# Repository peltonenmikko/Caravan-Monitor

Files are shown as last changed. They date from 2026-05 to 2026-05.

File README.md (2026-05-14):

# Caravan-Monitor
For monitoring caravan stuff

This is an STM32 powered monitoring station for different kinds of sensors made with caravans in mind.
It is powered by 12v car batteries. All other are off the board and connected with wires.

It shows the values on a cheap I²C OLED display and there is one button to browse the values.
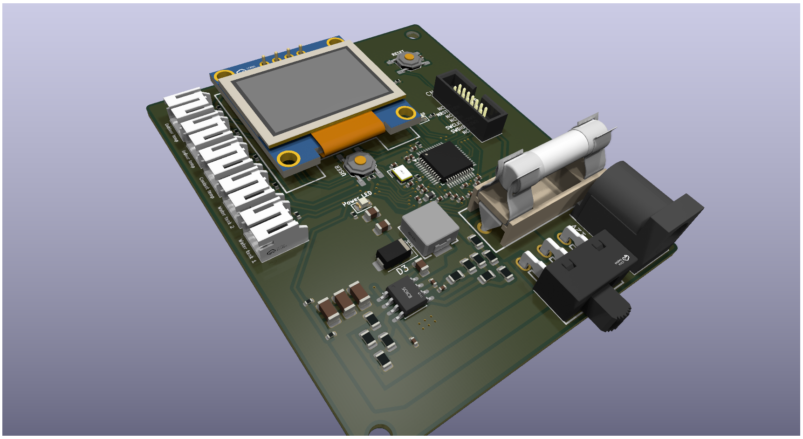
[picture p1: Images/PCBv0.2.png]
Version 0.2 of PCB


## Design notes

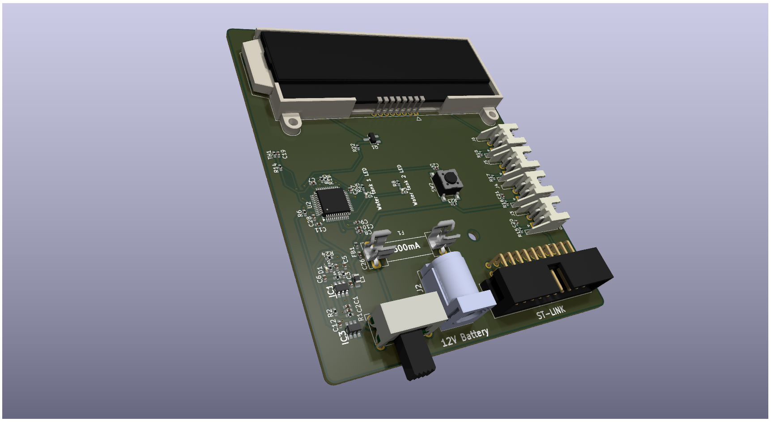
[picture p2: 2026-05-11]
Images/PCB.png

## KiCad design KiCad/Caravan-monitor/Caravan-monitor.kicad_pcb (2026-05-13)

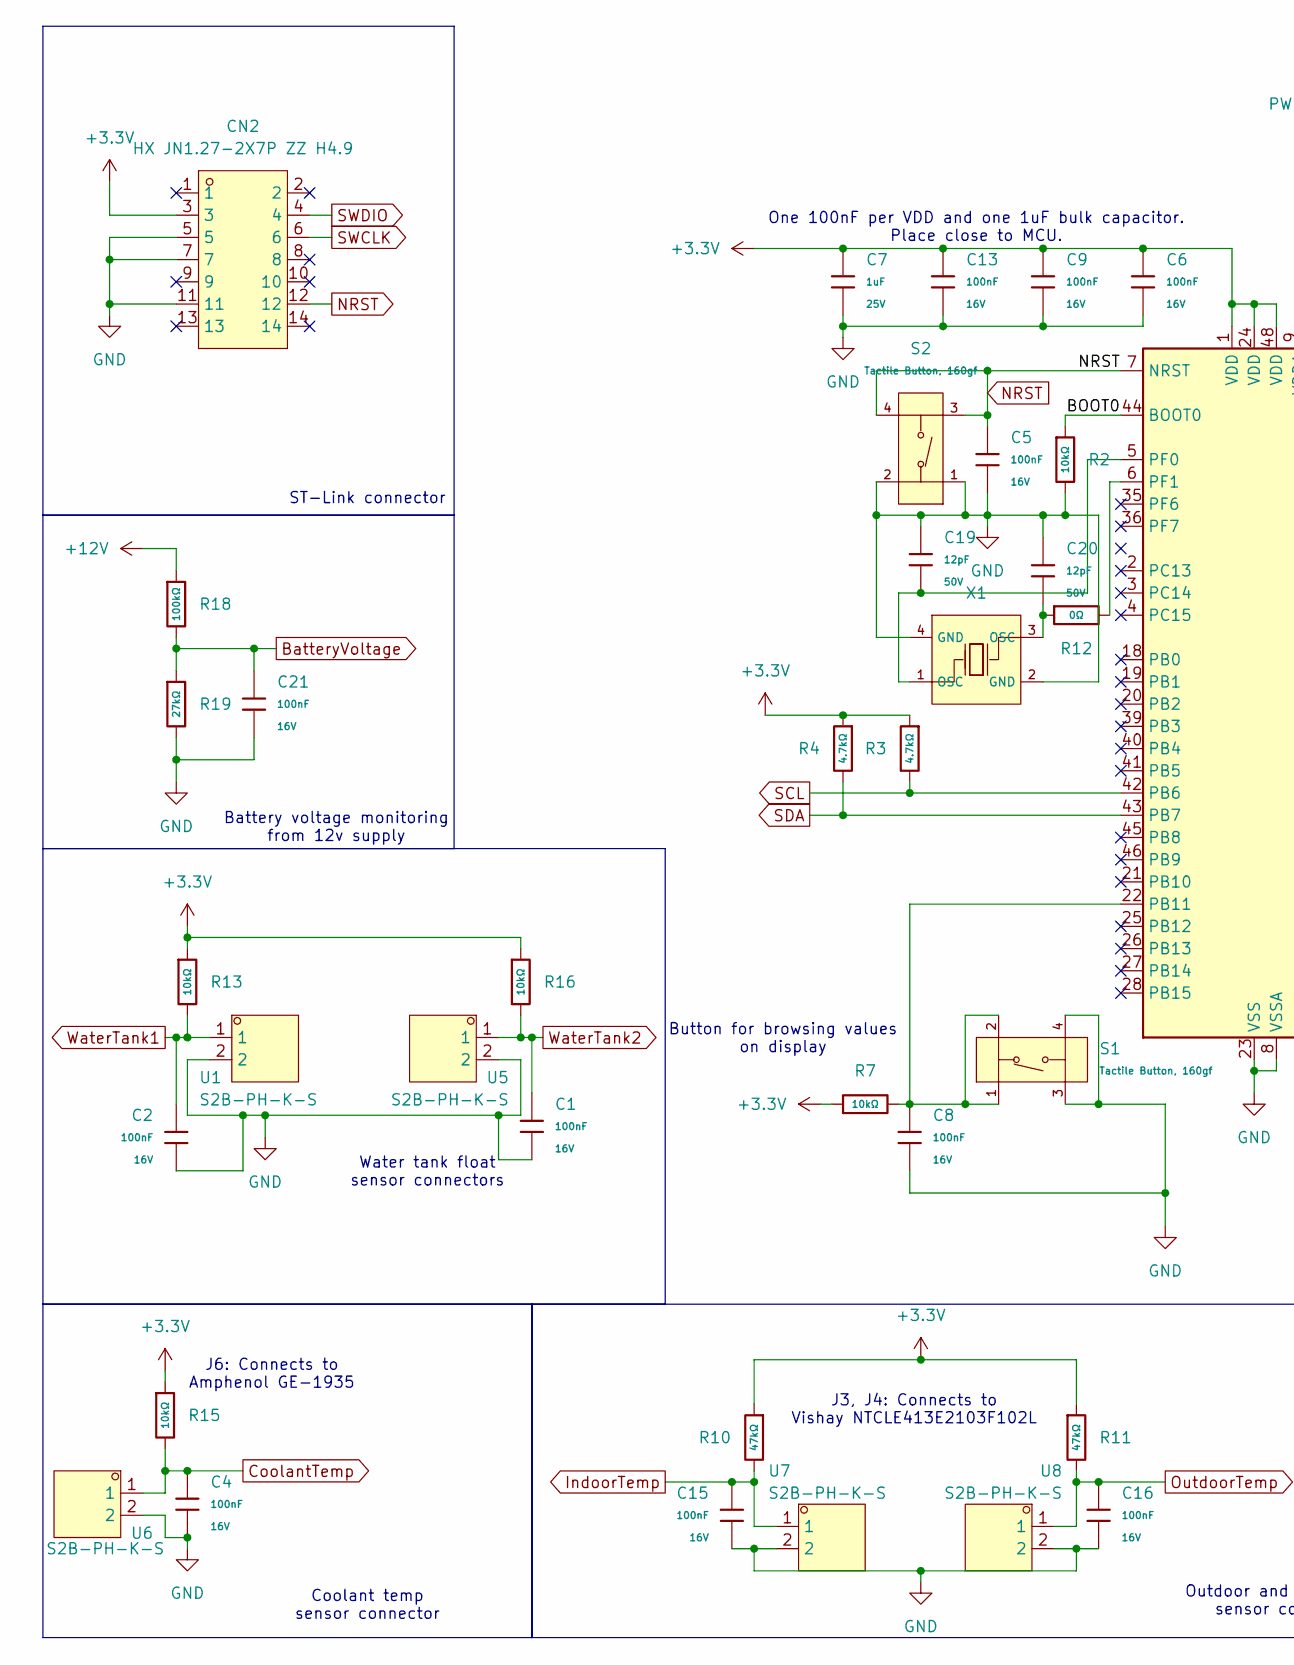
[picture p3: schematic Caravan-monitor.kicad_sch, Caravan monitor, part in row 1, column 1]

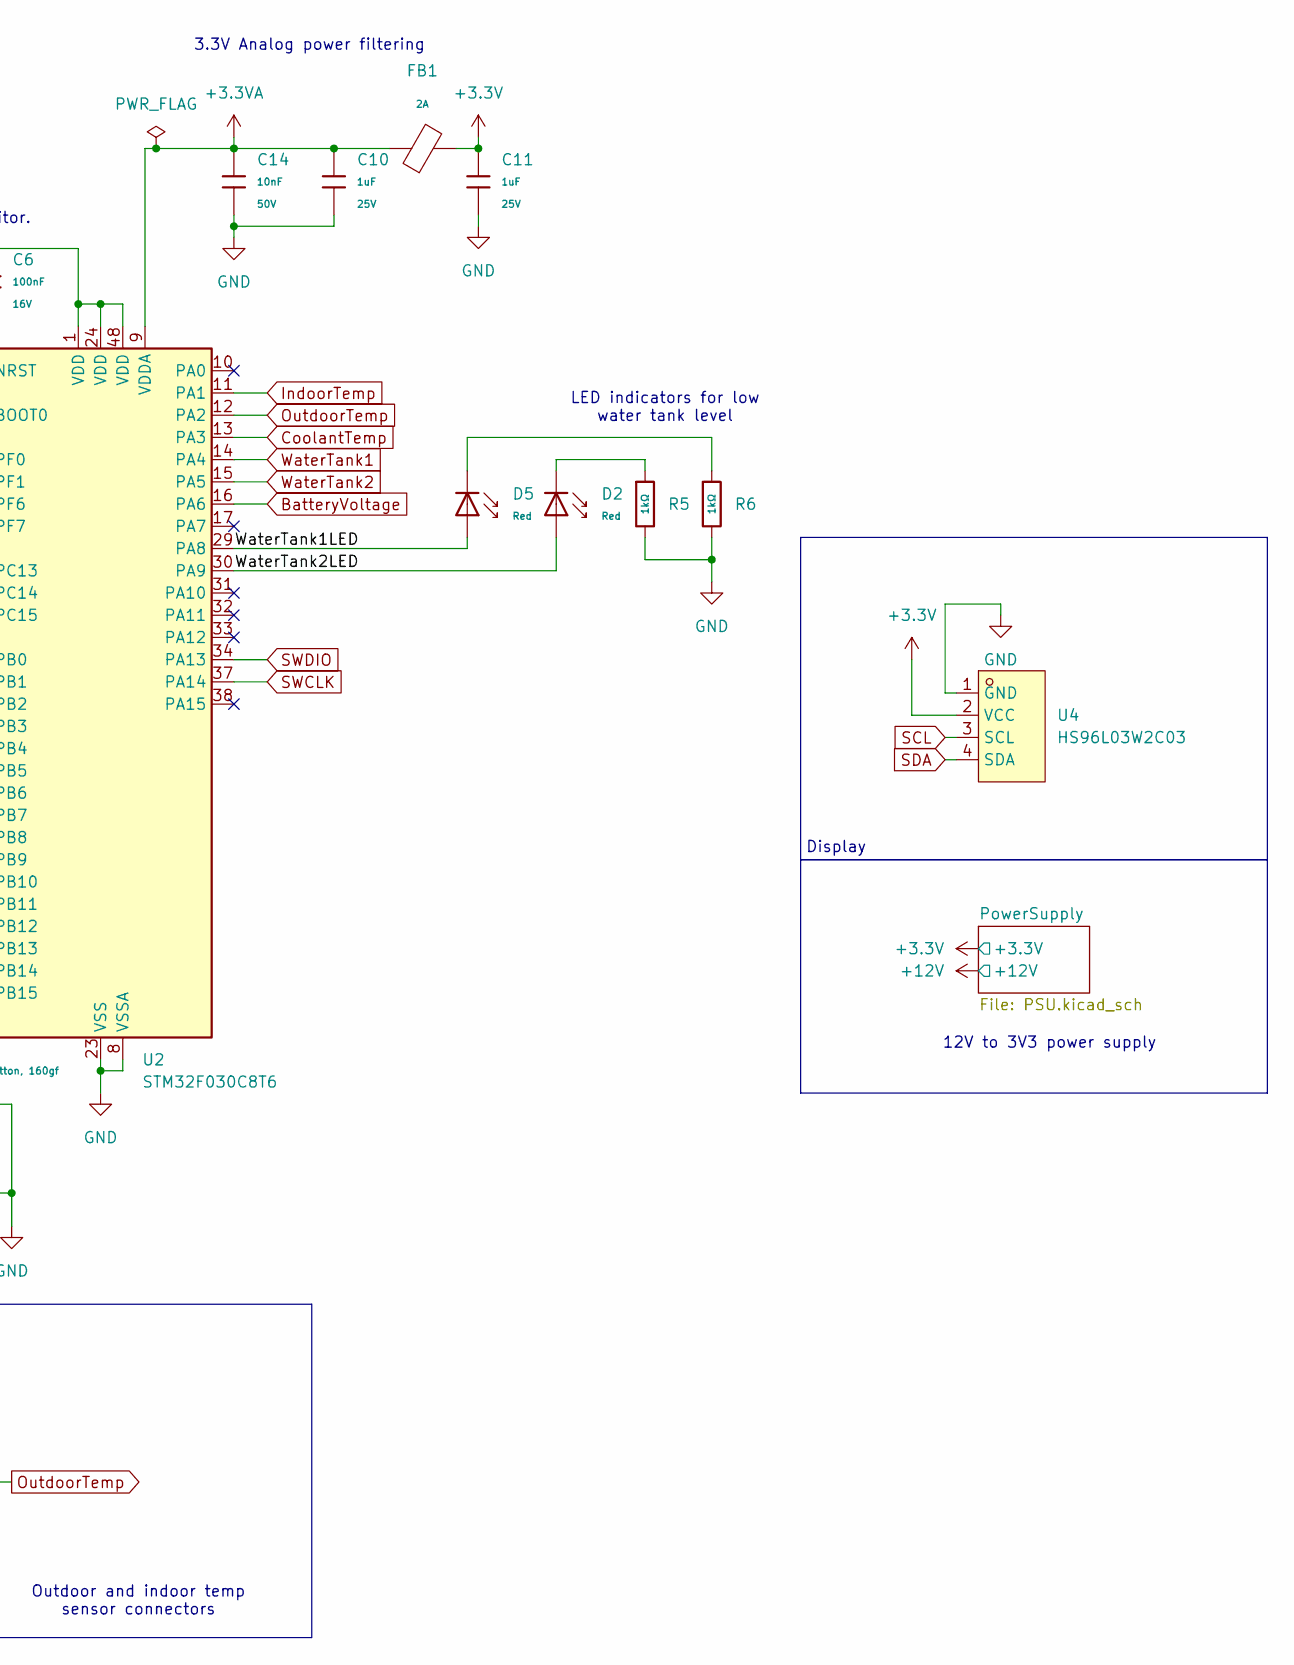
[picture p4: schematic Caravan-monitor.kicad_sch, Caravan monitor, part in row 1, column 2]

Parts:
C1, C2, C4, C5, C6, C8, C9, C13, C15, C16, C21: 100nF; C_0402; Voltage Rated 16V; Tolerance ±10%; Part CL05B104KO5NNNC; LCSC C1525
C7, C10, C11: 1uF; C_0402; Voltage Rated 25V; Tolerance ±10%; Part CL05A105KA5NQNC; LCSC C52923
C14: 10nF; C_0402; Voltage Rated 50V; Tolerance ±10%; Part CL05B103KB5NNNC; LCSC C15195
C19, C20: 12pF; C_0402; Voltage Rated 50V; Tolerance ±5%; Part 0402CG120J500NT; LCSC C1547
CN2: HX JN1.27-2X7P ZZ H4.9; IDC-TH_14P-P1.27_C42455940; MPN HX JN1.27-2x7P ZZ H4.9; LCSC Part C42455940
D2, D5: Red; D_0603; Part KT-0603R; LCSC C2286
FB1: FB_0603; Current Rating 2A; Tolerance ±25%; Part BLM18PG121SN1D; LCSC C14709
R2, R7, R13, R15, R16: 10kΩ; R_0402; Overload Voltage (Max) 50V; Tolerance ±1%; Part 0402WGF1002TCE; LCSC C25744
R3, R4: 4.7kΩ; R_0402; Overload Voltage (Max) 50V; Tolerance ±1%; Part 0402WGF4701TCE; LCSC C25900
R5, R6: 1kΩ; R_0402; Overload Voltage (Max) 50V; Tolerance ±1%; Part 0402WGF1001TCE; LCSC C11702
R10, R11: 47kΩ; R_0402; Overload Voltage (Max) 50V; Tolerance ±1%; Part 0402WGF4702TCE; LCSC C25792
R12: 0Ω; R_0402; Overload Voltage (Max) 50V; Tolerance ±1%; Part 0402WGF0000TCE; LCSC C17168
R18: 100kΩ; R_0402; Overload Voltage (Max) 50V; Tolerance ±1%; Part 0402WGF1003TCE; LCSC C25741
R19: 27kΩ; R_0402; Overload Voltage (Max) 50V; Tolerance ±1%; Part 0402WGF2702TCE; LCSC C25771
S1, S2: Tactile Button, 160gf; SW-SMD_4P-L5.1-W5.1-P3.70-LS6.5-TL-2; Voltage Rating (Dc) 12V; Part TS-1187A-B-A-B; LCSC C318884
U1, U5, U6, U7, U8: S2B-PH-K-S; CONN-TH_S2B-PH-K-S-LF-SN; MPN S2B-PH-K-S(LF)(SN); LCSC Part C173752
U2: STM32F030C8T6; LQFP-48_7x7mm_P0.5mm; Operating Voltage Range 2.4V~3.6V; Low Voltage Detection T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 2.4V~3.6V; Part STM32F030C8T6; LCSC C23922
U4: HS96L03W2C03; OLED-TH_L27.8-W27.2-P2.54_C9900033791; MPN HS96L03W2C03; LCSC Part C5248080
X1: X322516MLB4SI; OSC-SMD_4P-L3.2-W2.5-BL; Frequency Tolerance ±10ppm; Part X322516MLB4SI; LCSC C13738

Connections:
+3.3V: C6.1, C7.1, C9.1, C11.1, C13.1, CN2.3, FB1.2, R3.1, R4.1, R7.1, R10.1, R11.1, R13.1, R15.1, R16.1, U2.1 (VDD), U2.24 (VDD), U2.48 (VDD), U4.2 (VCC); also elsewhere on the board
+3.3VA: C10.1, C14.1, FB1.1, U2.9 (VDDA)
+12V: R18.1; also elsewhere on the board
/BOOT0: R2.1, U2.44 (BOOT0)
/WaterTank1LED: D5.2, U2.29 (PA8)
/WaterTank2LED: D2.2, U2.30 (PA9)
BatteryVoltage: C21.1, R18.2, R19.1, U2.16 (PA6)
CoolantTemp: C4.1, R15.2, U2.13 (PA3), U6.1
GND: C1.2, C2.2, C4.2, C5.2, C6.2, C7.2, C8.2, C9.2, C10.2, C11.2, C13.2, C14.2, C15.2, C16.2, C19.1, C20.1, C21.2, CN2.5, CN2.7, CN2.11, R2.2, R5.2, R6.2, R19.2, S1.3 (C), S1.4 (D), S2.1 (A), S2.2 (B), U1.2, U2.8 (VSSA), U2.23 (VSS), U2.47 (VSS), U4.1 (GND), U5.2, U6.2, U7.2, U8.2, X1.2 (GND), X1.4 (GND); also elsewhere on the board
IndoorTemp: C15.1, R10.2, U2.11 (PA1), U7.1
NRST: C5.1, CN2.12, S2.3 (C), S2.4 (D), U2.7 (NRST)
unnamed: C20.2, R12.1, X1.3 (OSC)
unnamed: D2.1, R5.1
unnamed: D5.1, R6.1
unnamed: C8.1, R7.2, S1.1 (A), S1.2 (B), U2.22 (PB11)
unnamed: C19.2, U2.5 (PF0), X1.1 (OSC)
unnamed: R12.2, U2.6 (PF1)
OutdoorTemp: C16.1, R11.2, U2.12 (PA2), U8.1
SCL: R3.2, U2.42 (PB6), U4.3 (SCL)
SDA: R4.2, U2.43 (PB7), U4.4 (SDA)
SWCLK: CN2.6, U2.37 (PA14)
SWDIO: CN2.4, U2.34 (PA13)
WaterTank1: C2.1, R13.2, U1.1, U2.14 (PA4)
WaterTank2: C1.1, R16.2, U2.15 (PA5), U5.1

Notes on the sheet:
One 100nF per VDD and one 1uF bulk capacitor. Place close to MCU.
Display
Water tank float sensor connectors
J6: Connects to Amphenol GE-1935
Battery voltage monitoring from 12v supply
Button for browsing values on display
3.3V Analog power filtering
Outdoor and indoor temp sensor connectors
LED indicators for low water tank level
Coolant temp sensor connector
12V to 3V3 power supply
ST-Link connector
J3, J4: Connects to Vishay NTCLE413E2103F102L

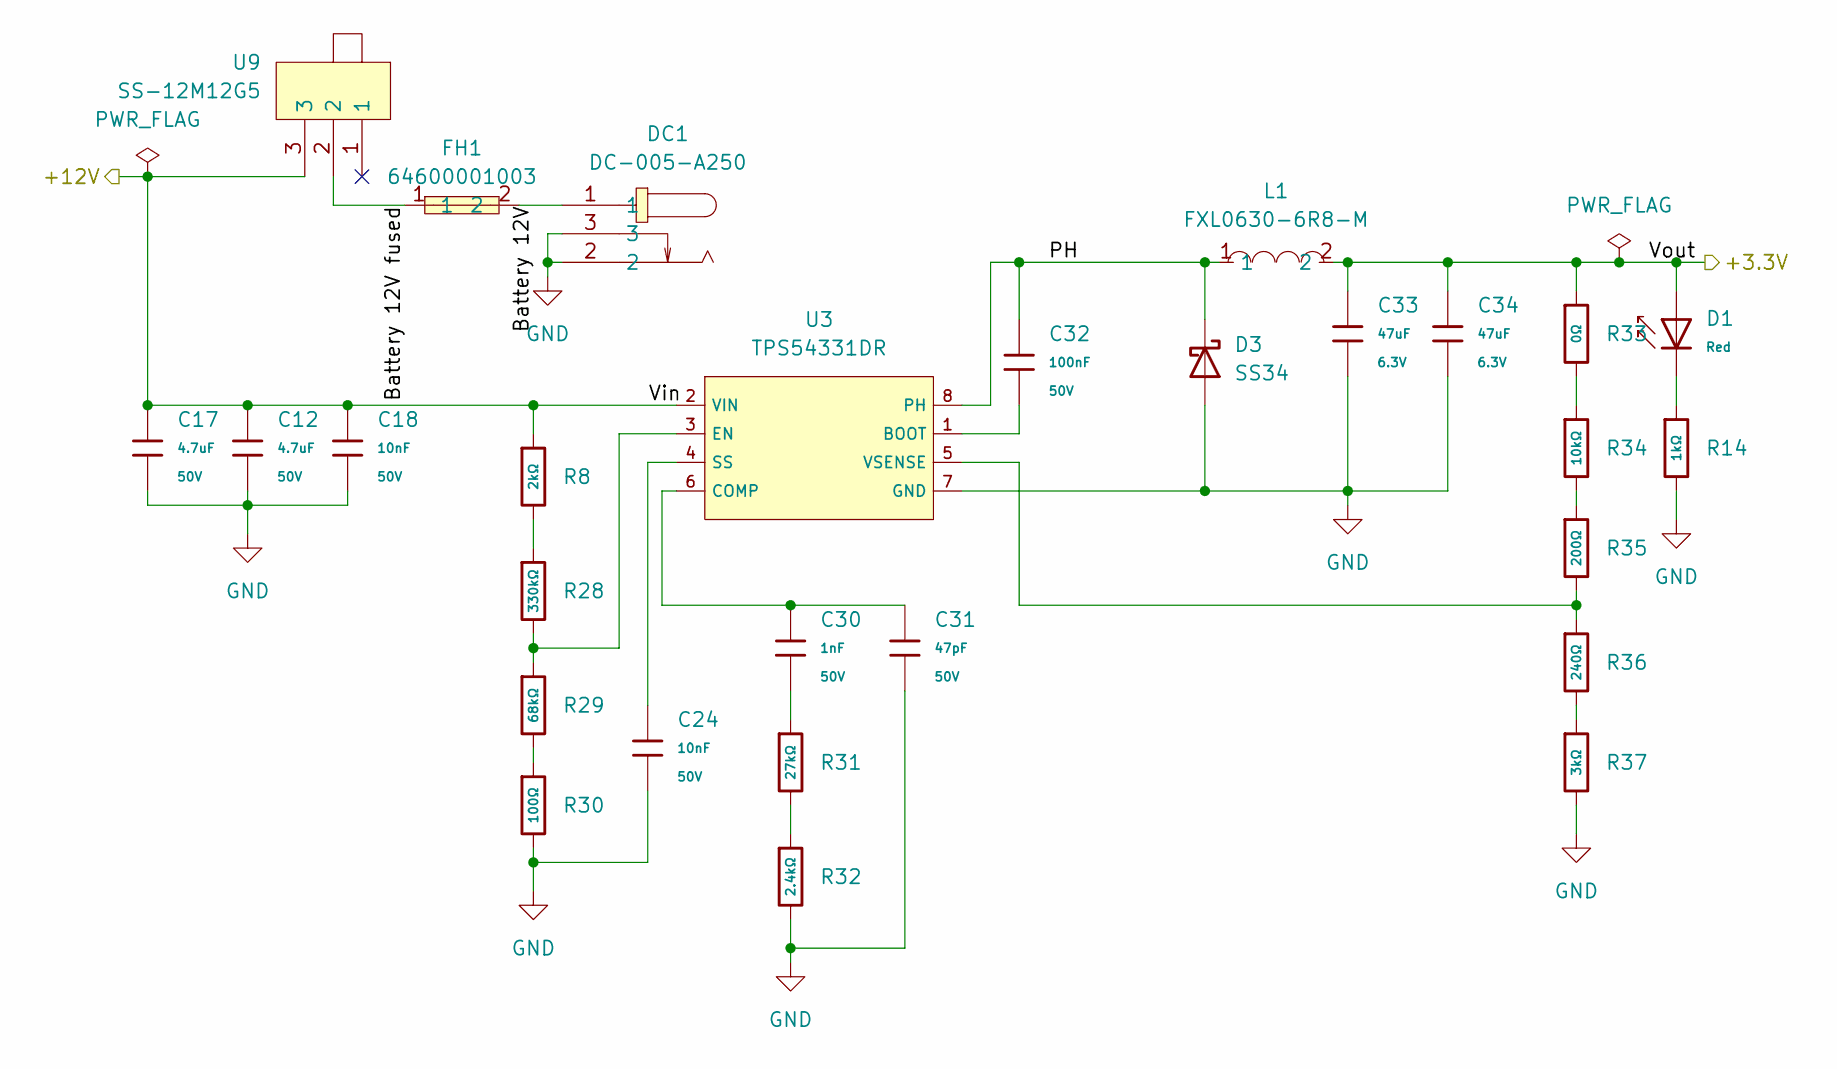
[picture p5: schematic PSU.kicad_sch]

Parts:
C12, C17: 4.7uF; C_1206; Voltage Rated 50V; Tolerance ±10%; Part 1206B475K500NT; LCSC C29823
C18: 10nF; C_1206; Voltage Rated 50V; Tolerance ±10%; Part 1206B103K500NT; LCSC C1846
C24: 10nF; C_0402; Voltage Rated 50V; Tolerance ±10%; Part CL05B103KB5NNNC; LCSC C15195
C30: 1nF; C_0402; Voltage Rated 50V; Tolerance ±10%; Part 0402B102K500NT; LCSC C1523
C31: 47pF; C_0402; Voltage Rated 50V; Tolerance ±5%; Part 0402CG470J500NT; LCSC C1567
C32: 100nF; C_0805; Voltage Rated 50V; Tolerance ±10%; Part CC0805KRX7R9BB104; LCSC C49678
C33, C34: 47uF; C_0805; Voltage Rated 6.3V; Tolerance ±20%; Part CL21A476MQYNNNE; LCSC C16780
D1: Red; D_0805; Forward Voltage (VF) 1.6V~2.6V; Part NCD0805R1; LCSC C84256
D3: SS34; D_SMA
DC1: DC-005-A250; DC-IN-TH_DC-005-A250; MPN DC-005-A250; LCSC Part C720558
FH1: 64600001003; MPN 64600001003; LCSC Part C206887
L1: FXL0630-6R8-M; IND-SMD_L7.0-W6.6; MPN FXL0630-6R8-M; LCSC Part C167221
R8: 2kΩ; R_0805; Overload Voltage (Max) 150V; Tolerance ±1%; Part 0805W8F2001T5E; LCSC C17604
R14: 1kΩ; R_0402; Overload Voltage (Max) 50V; Tolerance ±1%; Part 0402WGF1001TCE; LCSC C11702
R28: 330kΩ; R_0805; Overload Voltage (Max) 150V; Tolerance ±1%; Part 0805W8F3303T5E; LCSC C17629
R29: 68kΩ; R_0805; Overload Voltage (Max) 150V; Tolerance ±1%; Part 0805W8F6802T5E; LCSC C17801
R30: 100Ω; R_0805; Overload Voltage (Max) 150V; Tolerance ±1%; Part 0805W8F1000T5E; LCSC C17408
R31: 27kΩ; R_0805; Overload Voltage (Max) 150V; Tolerance ±1%; Part 0805W8F2702T5E; LCSC C17593
R32: 2.4kΩ; R_0805; Overload Voltage (Max) 150V; Tolerance ±1%; Part 0805W8F2401T5E; LCSC C17526
R33: 0Ω; R_0805; Overload Voltage (Max) 150V; Tolerance ±1%; Part 0805W8F0000T5E; LCSC C17477
R34: 10kΩ; R_0805; Overload Voltage (Max) 150V; Tolerance ±1%; Part 0805W8F1002T5E; LCSC C17414
R35: 200Ω; R_0805; Overload Voltage (Max) 150V; Tolerance ±1%; Part 0805W8F2000T5E; LCSC C17540
R36: 240Ω; R_0805; Overload Voltage (Max) 150V; Tolerance ±1%; Part 0805W8F2400T5E; LCSC C17572
R37: 3kΩ; R_0805; Overload Voltage (Max) 150V; Tolerance ±1%; Part 0805W8F3001T5E; LCSC C17661
U3: TPS54331DR; SOIC-8_L5.0-W4.0-P1.27-LS6.0-BL; Output Voltage 0.8V~25V; Input Voltage 3.5V~28V; Part TPS54331DR; LCSC C9865
U9: SS-12M12G5; SW-TH_SS-12M12G5; MPN SS-12M12G5; LCSC Part C2884789

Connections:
+3.3V: C33.1, C34.1, D1.2, L1.2, R33.1; also elsewhere on the board
+12V: C12.1, C17.1, C18.1, R8.1, U3.2 (VIN), U9.3; also elsewhere on the board
/PowerSupply/Battery 12V: DC1.1, FH1.2
/PowerSupply/Battery 12V fused: FH1.1, U9.2
/PowerSupply/PH: C32.1, D3.1 (K), L1.1, U3.8 (PH)
GND: C12.2, C17.2, C18.2, C24.2, C31.2, C33.2, C34.2, D3.2 (A), DC1.2, DC1.3, R14.2, R30.2, R32.2, R37.2, U3.7 (GND); also elsewhere on the board
unnamed: C30.2, R31.1
unnamed: D1.1, R14.1
unnamed: R8.2, R28.1
unnamed: R29.2, R30.1
unnamed: R31.2, R32.1
unnamed: R33.2, R34.1
unnamed: R34.2, R35.1
unnamed: R36.2, R37.1
unnamed: C32.2, U3.1 (BOOT)
unnamed: C30.1, C31.1, U3.6 (COMP)
unnamed: R28.2, R29.1, U3.3 (EN)
unnamed: C24.1, U3.4 (SS)
unnamed: R35.2, R36.1, U3.5 (VSENSE)

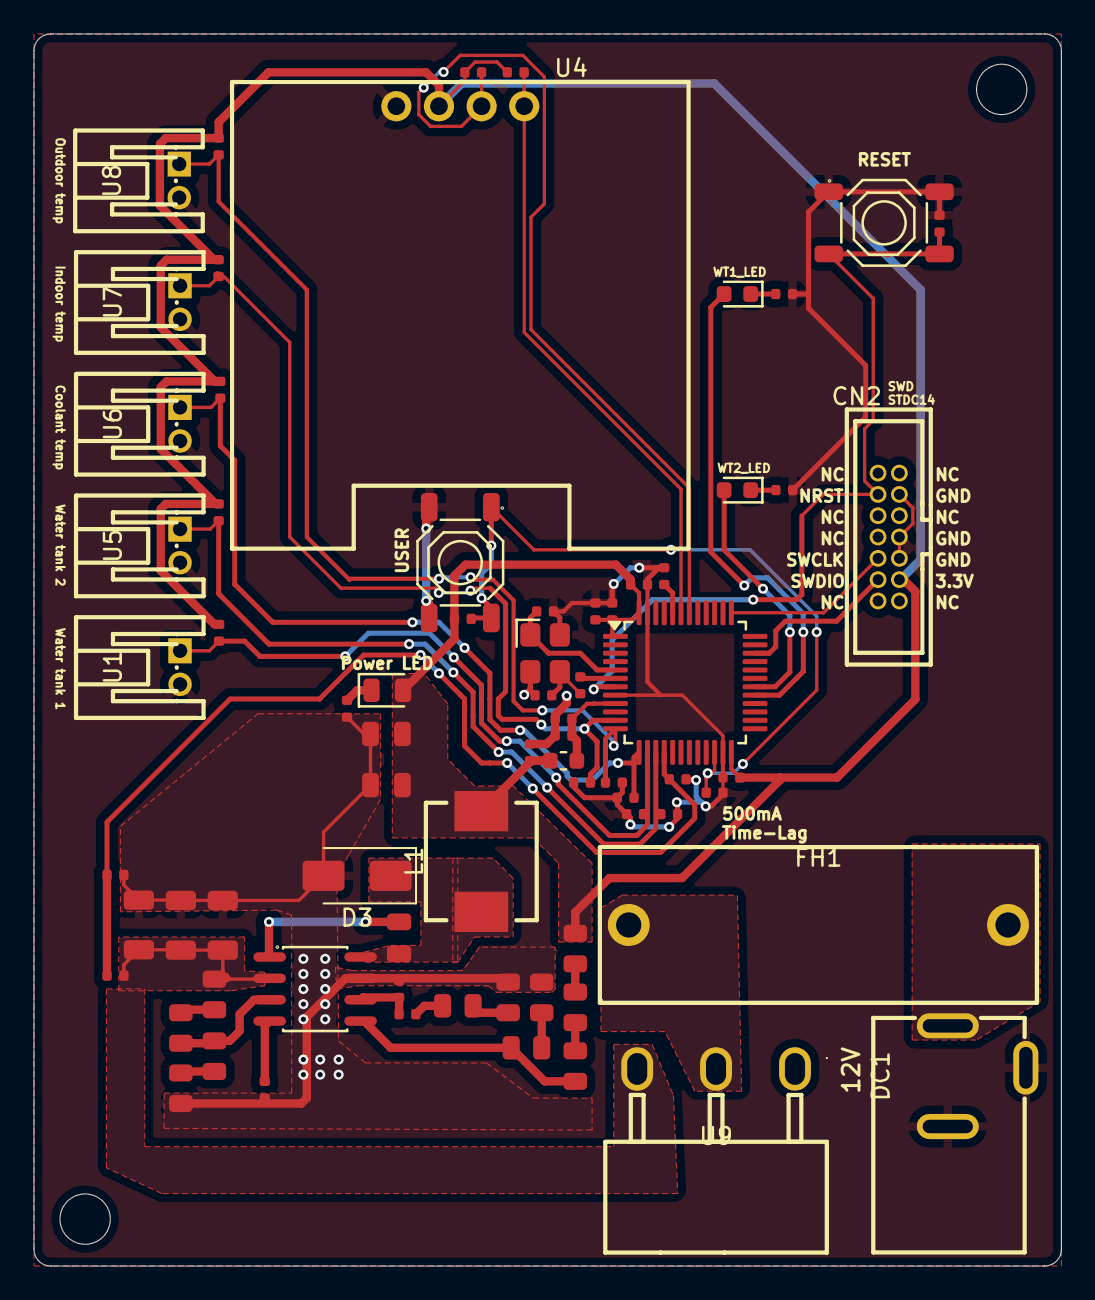
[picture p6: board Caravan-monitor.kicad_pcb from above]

Board: 2 copper layers, 61.2 x 73.4 mm, 73 parts (0 on the bottom side), 40 nets.

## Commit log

2026-05-10 Create KiCad and LTSpice folders
2026-05-10 PSU schematic done
    [Caravan-monitor.kicad_pcb, Caravan-monitor.kicad_sch, PSU.kicad_sch]
2026-05-10 Battery voltage monitoring schematics
    [5VPSU.kicad_sch, Caravan-monitor.kicad_pcb, Caravan-monitor.kicad_sch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]
2026-05-10 Temperature monitoring schematics
    [Caravan-monitor.kicad_pcb, Caravan-monitor.kicad_sch, indoor_temperature.kicad_sch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]
2026-05-10 Coolant temoerature measurement
    [Caravan-monitor.kicad_sch, coolant_temperature.kicad_sch]
2026-05-10 Display schematics
    [Caravan-monitor.kicad_pcb, Caravan-monitor.kicad_sch, Display.kicad_sch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]
2026-05-11 Schematics done
    [5VPSU.kicad_sch, Caravan-monitor.kicad_pcb, Caravan-monitor.kicad_sch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]
2026-05-11 3.3V and 5V PSU layout done
    [Caravan-monitor.kicad_pcb, Caravan-monitor.kicad_sch]
2026-05-11 PCB Designed
    [Caravan-monitor.kicad_pcb, Caravan-monitor.kicad_sch, Display.kicad_sch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]
2026-05-11 Version 0.1 complete
    [Caravan-monitor.kicad_pcb, Caravan-monitor.kicad_sch]
2026-05-11 Add image of PCB
2026-05-11 Update README
    brief description and an image of pcb
2026-05-12 test v0.2 branch commit
    [PSU.kicad_sch]
2026-05-12 Schematic updates
    Parts changed for JLCPCB assembly compatibility
    [Caravan-monitor.kicad_sch, Display.kicad_sch, PSU.kicad_sch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]
2026-05-12 12V to 3.3V converter done
    [Caravan-monitor.kicad_pcb, Caravan-monitor.kicad_sch, PSU.kicad_sch]
2026-05-13 V0.2 PCB complete
    [Caravan-monitor.kicad_pcb, Caravan-monitor.kicad_sch, PSU.kicad_sch]
2026-05-13 Updated README with image of new PCB
